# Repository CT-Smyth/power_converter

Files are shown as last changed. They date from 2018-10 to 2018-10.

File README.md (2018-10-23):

VDM power_converter

A control system for controlling cheap power supply bricks (sold commonly as LED drivers, power supplies, etc) to make them suitable for battery charging or other low resistance variable loads. 

The circuit monitors current output from the power supply with a hall effect sensor, and adjusts a digipot which is wired to replace the trimmer pot normally used to adjust output voltage.

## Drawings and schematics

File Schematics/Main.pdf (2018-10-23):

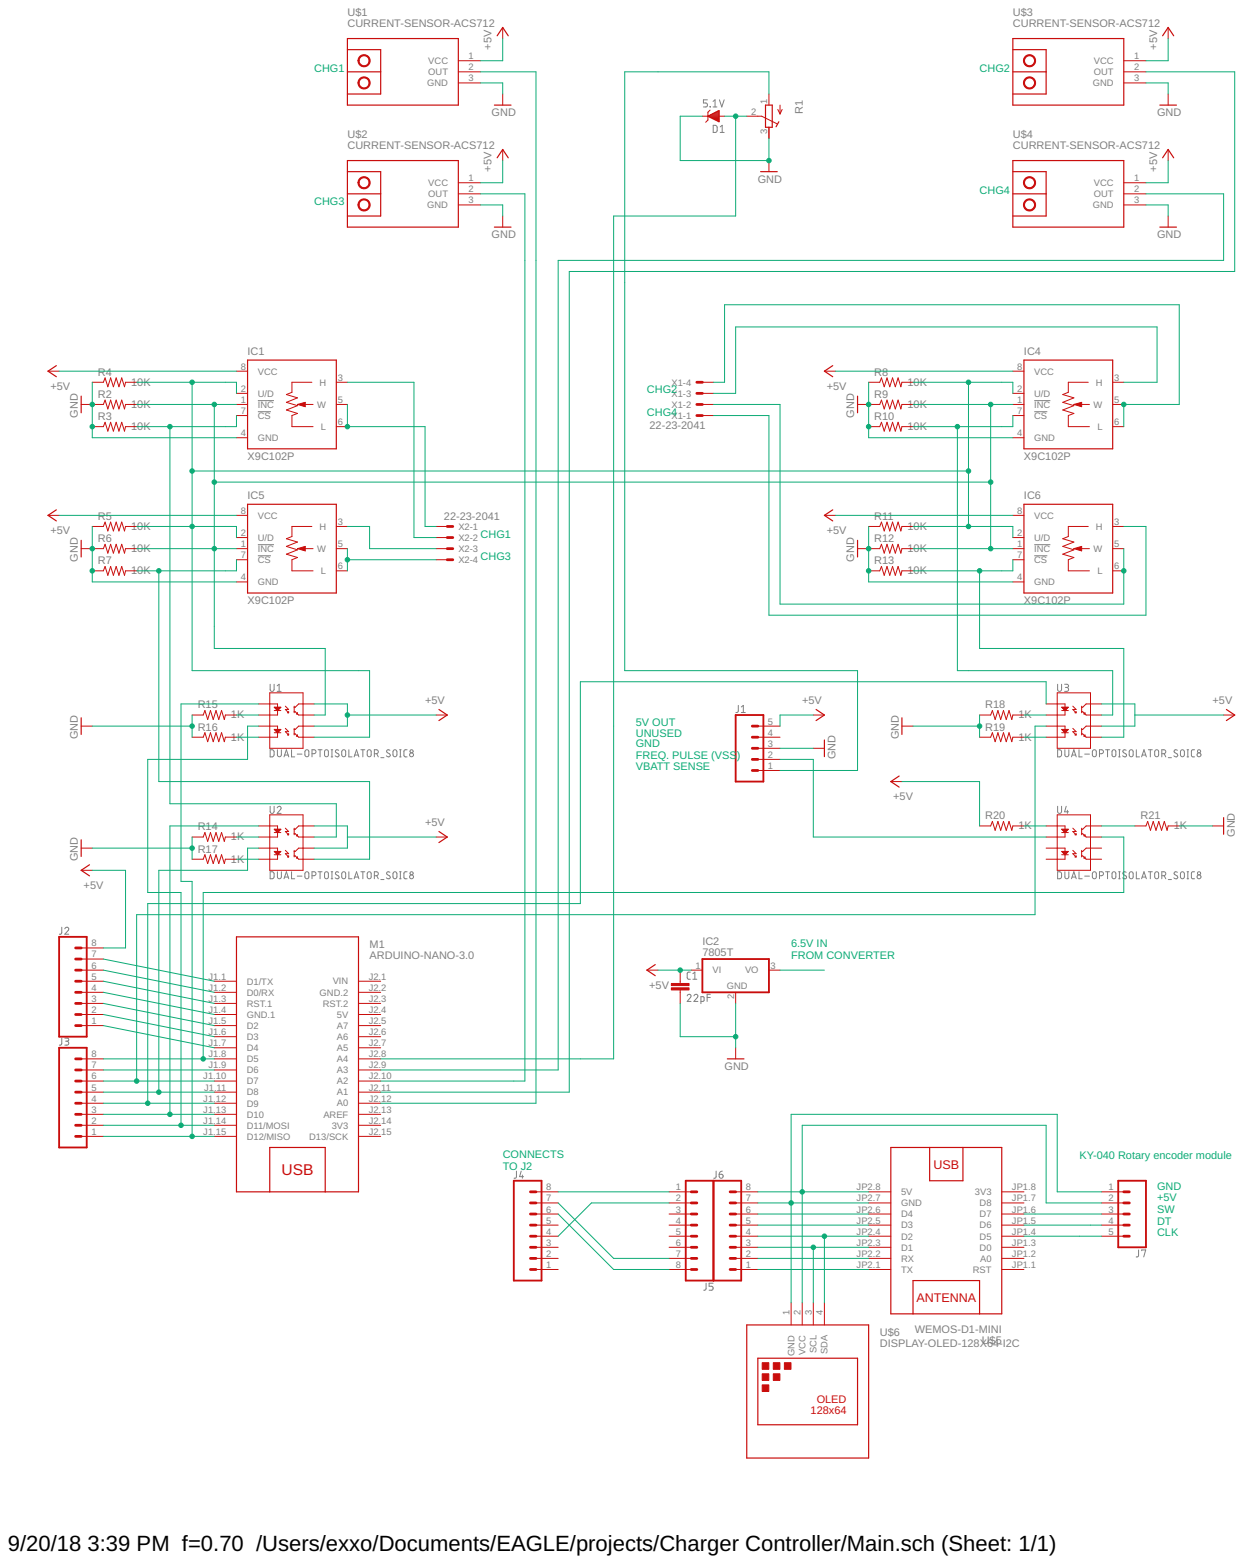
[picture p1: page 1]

FREQ. PULSE (VSS) VBATT SENSE

WEMOS-D1-MINI DISPLAY-OLED-128X64-I2C

9/20/18 3:39 PM f=0.70 /Users/exxo/Documents/EAGLE/projects/Charger Controller/Main.sch (Sheet: 1/1)

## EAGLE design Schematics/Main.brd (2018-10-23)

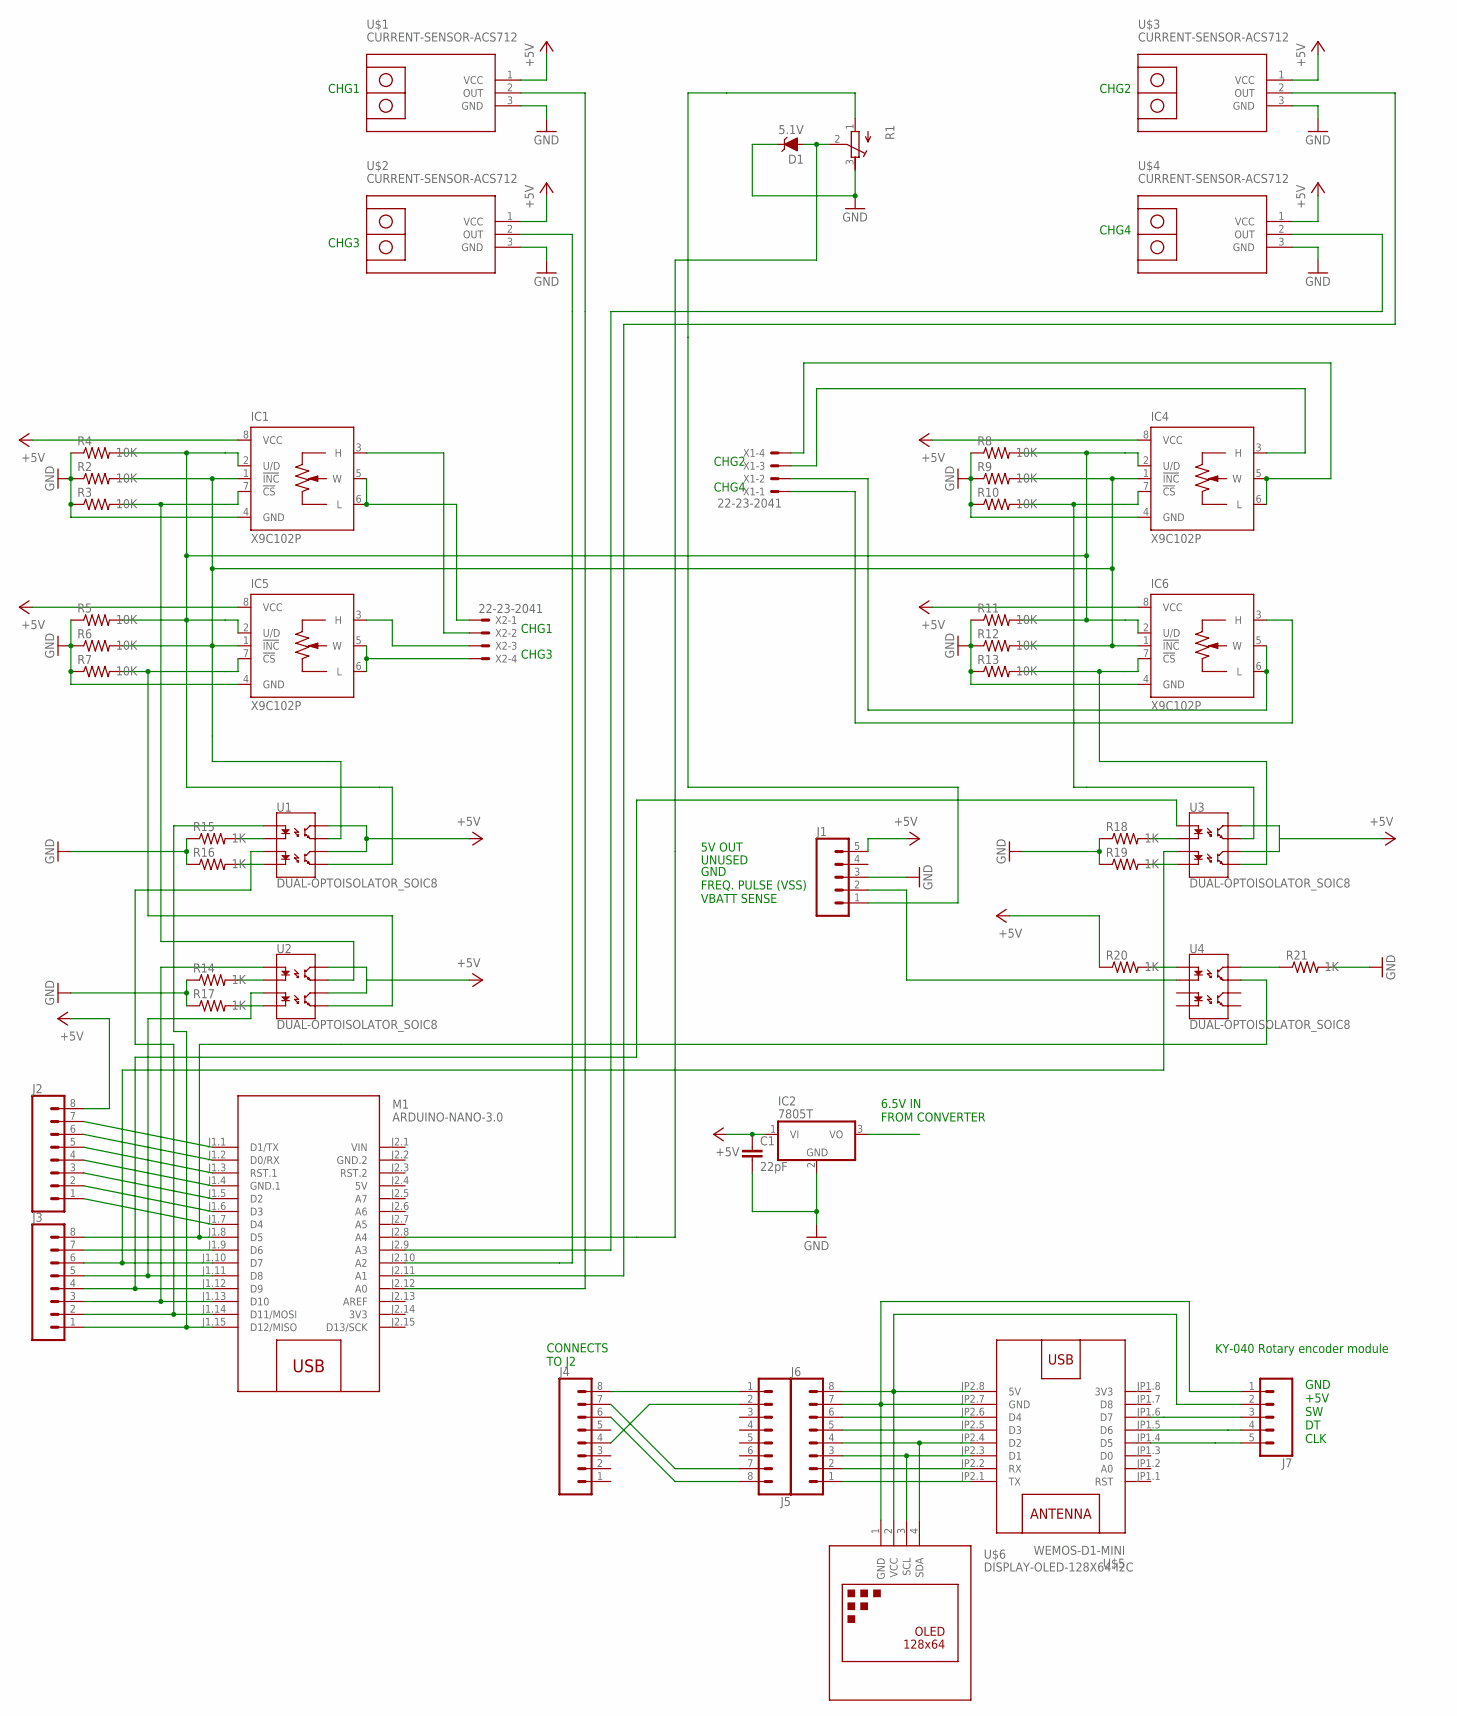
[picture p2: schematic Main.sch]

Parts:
C1: 22pF; CAP-PTH-2.54
D1: 5.1V; SOD-323
IC1, IC4, IC5, IC6: X9C102P; DIL08
IC2: 7805T; TO220H
J1, J7: CONN_05PTH_LONGPADS; 1X05_LONGPADS
J2, J3, J4, J5, J6: CONN_08LONGPADS; 1X08_LONGPADS
M1: ARDUINO-NANO-3.0
R1: R-TRIMM64W; RTRIM64W
R2, R3, R4, R5, R6, R7, R8, R9, R10, R11, R12, R13: 10K; 0204/7
R14, R15, R16, R17, R18, R19, R20, R21: 1K; 0204/7
U1, U2, U3, U4: DUAL-OPTOISOLATOR_SOIC8; SO08
U$1, U$2, U$3, U$4: CURRENT-SENSOR-ACS712
U$5: WEMOS-D1-MINI
U$6: DISPLAY-OLED-128X64-I2C
X1, X2: 22-23-2041

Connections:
3V3: M1.J2.14 (3V3), U$5.JP1.8 (3V3)
5V: M1.J2.4 (5V)
+5V: C1.1, IC1.8 (VCC), IC2.1 (VI), IC4.8 (VCC), IC5.8 (VCC), IC6.8 (VCC), J1.5, J2.8, R20.1, U1.6 (CL2), U1.8 (CL1), U2.6 (CL2), U2.8 (CL1), U3.6 (CL2), U3.8 (CL1), U$1.1 (VCC), U$2.1 (VCC), U$3.1 (VCC), U$4.1 (VCC)
GND: C1.2, D1.C, IC1.4 (GND), IC2.2 (GND), IC4.4 (GND), IC5.4 (GND), IC6.4 (GND), J1.3, R1.3 (E), R2.1, R3.1, R4.1, R5.1, R6.1, R7.1, R8.1, R9.1, R10.1, R11.1, R12.1, R13.1, R14.1, R15.1, R16.1, R17.1, R18.1, R19.1, R21.2, U$1.3 (GND), U$2.3 (GND), U$3.3 (GND), U$4.3 (GND)
GND.2: M1.J2.2 (GND.2)
unnamed: IC1.7 (!CS), R3.2, U2.7 (EM1)
unnamed: IC1.1 (!INC), IC4.1 (!INC), IC5.1 (!INC), IC6.1 (!INC), R2.2, R6.2, R9.2, R12.2, U1.7 (EM1)
unnamed: R15.2, U1.2 (C1)
unnamed: IC1.5 (W), IC1.6 (L), X2.1
unnamed: R16.2, U1.4 (C2)
unnamed: IC5.7 (!CS), R7.2, U2.5 (EM2)
unnamed: IC1.3 (H), X2.2
unnamed: IC1.2 (U/D), IC4.2 (U/D), IC5.2 (U/D), IC6.2 (U/D), R4.2, R5.2, R8.2, R11.2, U1.5 (EM2)
unnamed: IC5.5 (W), IC5.6 (L), X2.4
unnamed: IC5.3 (H), X2.3
unnamed: R14.2, U2.2 (C1)
unnamed: R17.2, U2.4 (C2)
unnamed: IC4.5 (W), IC4.6 (L), X1.4
unnamed: IC6.7 (!CS), R13.2, U3.5 (EM2)
unnamed: R18.2, U3.2 (C1)
unnamed: R19.2, U3.4 (C2)
unnamed: IC6.5 (W), IC6.6 (L), X1.2
unnamed: IC4.3 (H), X1.3
unnamed: IC6.3 (H), X1.1
unnamed: IC4.7 (!CS), R10.2, U3.7 (EM1)
unnamed: J1.2, U4.2 (C1)
unnamed: J1.1, R1.1 (A)
unnamed: D1.A, M1.J2.8 (A4), R1.2 (S)
unnamed: J3.8, M1.J1.8 (D5), U4.7 (EM1)
unnamed: R20.2, U4.1 (A1)
unnamed: R21.1, U4.8 (CL1)
unnamed: J2.1, M1.J1.7 (D4)
unnamed: J2.2, M1.J1.6 (D3)
unnamed: J2.3, M1.J1.5 (D2)
unnamed: J2.4, M1.J1.4 (GND.1)
unnamed: J2.5, M1.J1.3 (RST.1)
unnamed: J2.6, M1.J1.2 (D0/RX)
unnamed: J2.7, M1.J1.1 (D1/TX)
unnamed: J3.1, M1.J1.15 (D12/MISO), U1.1 (A1)
unnamed: J3.2, M1.J1.14 (D11/MOSI), U1.3 (A2)
unnamed: J3.3, M1.J1.13 (D10), U2.1 (A1)
unnamed: J3.4, M1.J1.12 (D9), U3.1 (A1)
unnamed: J3.5, M1.J1.11 (D8), U2.3 (A2)
unnamed: J3.6, M1.J1.10 (D7), U3.3 (A2)
unnamed: J3.7, M1.J1.9 (D6)
unnamed: M1.J2.12 (A0), U$1.2 (OUT)
unnamed: M1.J2.10 (A2), U$2.2 (OUT)
unnamed: M1.J2.11 (A1), U$3.2 (OUT)
unnamed: M1.J2.9 (A3), U$4.2 (OUT)
unnamed: J6.1, U$5.JP2.1 (TX)
unnamed: J6.2, U$5.JP2.2 (RX)
unnamed: J6.3, U$5.JP2.3 (D1), U$6.3 (SCL)
unnamed: J6.4, U$5.JP2.4 (D2), U$6.4 (SDA)
unnamed: J6.5, U$5.JP2.5 (D3)
unnamed: J6.6, U$5.JP2.6 (D4)
unnamed: J6.7, J7.1, U$5.JP2.7 (GND), U$6.1 (GND)
unnamed: J6.8, J7.2, U$5.JP2.8 (5V), U$6.2 (VCC)
unnamed: J4.8, J5.1
unnamed: J4.4, J5.2
unnamed: J4.7, J5.7
unnamed: J4.6, J5.8
unnamed: J7.3, U$5.JP1.6 (D7)
unnamed: J7.4, U$5.JP1.5 (D6)
unnamed: J7.5, U$5.JP1.4 (D5)
VIN: M1.J2.1 (VIN)

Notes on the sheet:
5V OUT
UNUSED
GND FREQ. PULSE (VSS) VBATT SENSE
CHG1
CHG3
CHG2
CHG4
6.5V IN FROM CONVERTER
CONNECTS TO J2
KY-040 Rotary encoder module
GND +5V SW DT CLK

Board: 2 copper layers, 48 parts (0 on the bottom side), 62 nets, no tracks yet.

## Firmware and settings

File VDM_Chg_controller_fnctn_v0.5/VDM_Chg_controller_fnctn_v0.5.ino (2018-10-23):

//for Arduino Nano or ATMega328PA or equivelant
 
//#include <FreqCount.h>

#define INC 12   // D1 Mini D4 - pulled up in H/W (10k) ->  chip pin 1
#define UD 11  // D1 Mini D8                          ->  chip pin 2
#define CS1 10   // D1 Mini D0 - pulled up in H/W (10k) ->  2nd chip pin 7
#define CS2 9
#define CS3 8
#define CS4 7
#define freqPin 5
#define current1Pin A0
#define current2Pin A1
#define current3Pin A2
#define current4Pin A3
#define voltagePin A4


// "up" and "down" make sense in relation to the wiper pin 5 [VW/RW] and the HIGH end of the pot
// i.e. pin 3 [VH/RH], leaving pin 6 [VL/RL] unused (floating). You can easily use pin 6 instead
// pin 3, but "min" will actually mean "max" and vice versa. Also, the "setPot" percentage will
// set the equivalent of 100-<value>, i.e. setPot(70) will set the resistance between pins 5 and 6 
// to 30% of the maximum. (Of course in that case,the "unused" resistance between 5 and 3 will be 70%)
// Nothing to stop you using it as a full centre-tap potentiometer, the above example giving
// pin 3[H] -- 70% -- pin 5[W] -- 30% -- pin 6[L]



bool  bulkMode = true;


int pulseHigh; // Integer variable to capture High time of the incoming pulse
int pulseLow; // Integer variable to capture Low time of the incoming pulse


const int mVperAmp = 66; // use 185 for 5A Module, 100 for 20A Module and 66 for 30A Module
const int ACSoffset = 2500; //2500


int chgMode = 0;



float pulseTotal; // Float variable to capture Total time of the incoming pulse
float frequency; // Calculated Frequency

double Vtrig = 24;
double Vtarg = 27;
double VfloatMin = 26;
double VfloatMax = 26.5;
const double Vmax = 29.5;
const double Vmin = 18;

const double maxCurrent = 15;
const double targetCurrent = 12;



double Voltage = 0;


long num = 0;

unsigned long timeNow = millis();
const unsigned long disp_delay = 1000;
const unsigned long RPM_delay = 400; //2.5 times a second
const unsigned long chg_delay = 255; //4 times a second
unsigned long RPMTimeDue = timeNow + RPM_delay;
unsigned long dispTimeDue = timeNow + disp_delay;
unsigned long chgTimeDue = timeNow + chg_delay;


int incomingByte;      // a variable to read incoming serial data into



void setup(){
pinMode(freqPin,INPUT);

pinMode(INC,OUTPUT);
pinMode(UD,OUTPUT);
pinMode(CS1,OUTPUT);
pinMode(CS2,OUTPUT);
pinMode(CS3,OUTPUT);
pinMode(CS4,OUTPUT);

digitalWrite(UD,HIGH);
digitalWrite(INC,LOW);
digitalWrite(CS1,HIGH);
digitalWrite(CS2,HIGH);
digitalWrite(CS3,HIGH);
digitalWrite(CS4,HIGH);

digitalWrite (freqPin,true); //pullup
//FreqCount.begin(1000);
Serial.begin(57600); 
Serial.println("Energy converter function program");

pinMode(3,OUTPUT); //signal generator for testing
analogWrite(3,75); //signal generator for testing

//analogWrite (12,100);
//analogWrite (11,150);
//analogWrite(10,200);


//pot_1k_setval(1,20); //set these to test POT writing functions
//pot_1k_setval(2,40); //set these to test POT writing functions
//pot_1k_setval(3,60); //set these to test POT writing functions
//pot_1k_setval(4,80); //set these to test POT writing functions


}





void loop() { 

timeNow = millis(); 
  
  
if (Serial.available() > 0) {
    // read the oldest byte in the serial buffer:
    incomingByte = Serial.read();

    if (incomingByte == '0') chgMode = 0;

    if (incomingByte == '1') chgMode = 1;

    if (incomingByte == '2') chgMode = 2;

    if (incomingByte == '3') chgMode = 3;

    
    
//  Serial.print("Operation Mode = ");
//  Serial.println(chgMode);  
}





if (timeNow > chgTimeDue) chargeControl();
if (timeNow > dispTimeDue) one_sec();
// if (timeNow > RPMTimeDue) get_RPM();
 
}

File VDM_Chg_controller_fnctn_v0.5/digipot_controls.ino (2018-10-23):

void pot_down(int potNumber){
  digitalWrite(INC,HIGH); //set up the increment line to increment on low transition & wiper safety
  delayMicroseconds(100);
  digitalWrite(UD,HIGH); //High for up, low for down
  delayMicroseconds(100);
  CS_low (potNumber);
  digitalWrite(INC,LOW); //move wiper as per UD bit
  delayMicroseconds(100);
  CS_high (potNumber);
}

void pot_up(int potNumber){
  digitalWrite(INC,HIGH); //set up the increment line to increment on low transition & wiper safety
  delayMicroseconds(100);
  digitalWrite(UD,LOW); //High for up, low for down
  delayMicroseconds(100);
  CS_low (potNumber);
  digitalWrite(INC,LOW); //move wiper as per UD bit
  delayMicroseconds(100);
  CS_high (potNumber);
}

void pot_store(int potNumber){
  delay(1);
  digitalWrite(INC,HIGH); //set up the increment line to increment on low transition & wiper safety
  delay(1);
  CS_low (potNumber); // Select Chip
  delay(1);
  CS_high (potNumber); //Deselect Chip (stores value because INC is high)
  delay(1);
}


void pot_1k_setval(int potNumber, int val){
  if (val > 100) val = 100;
  if (val < 0) val = 0;
  pot_to_1k(potNumber);
  val = 100 - val;
  for (int t = 0;t<val;t++){
    pot_down(potNumber);
  }  
}

void pot_0k_setval(int potNumber, int val){
  if (val > 100) val = 100;
  if (val < 0) val = 0;
  pot_to_0k(potNumber);
  for (int t = 0;t<val;t++){
    pot_up(potNumber);
  }  
}



void pot_to_1k(int potNumber){
  for (int t = 0;t<101;t++){
    pot_up(potNumber);
  }
}

void pot_to_0k(int potNumber){
  for (int t = 0;t<101;t++){
    pot_down(potNumber);
  }
}

void CS_high(int potNumber){
  
    switch (potNumber) {
    case 1:
      digitalWrite(CS1,HIGH); 
      break;
    case 2:
      digitalWrite(CS2,HIGH);
      break;
    case 3:
      digitalWrite(CS3,HIGH);
      break;
    case 4:
      digitalWrite(CS4,HIGH);
      break;
    default:
      Serial.println("Select_High Selection Error");
  }

  delayMicroseconds(100);
}



void CS_low(int potNumber){
  
    switch (potNumber) {
    case 1:
      digitalWrite(CS1,LOW);
      break;
    case 2:
      digitalWrite(CS2,LOW);
      break;
    case 3:
      digitalWrite(CS3,LOW);
      break;
    case 4:
      digitalWrite(CS4,LOW);
      break;
    default:
      Serial.println("Select_Low Selection Error");
  }

  delayMicroseconds(100);
}

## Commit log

2018-10-23 Added schematics
    [Main.brd, Main.sch]
2018-10-23 Changed filenames to reflect correct versioning
    [Display_subs.ino, Subs.ino, VDM_Chg_controller_fnctn_v0.5.ino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]
2018-10-23 Bug fixes, changed sample rate
    Increased analog sampling duration to ensure that 1/30th of a second is sampled for better accuracy.
    [Subs.ino, VDM_Chg_controller_fnctn_v0.5.ino]
2018-10-23 Directory name change
    [Main.brd, Main.sch]

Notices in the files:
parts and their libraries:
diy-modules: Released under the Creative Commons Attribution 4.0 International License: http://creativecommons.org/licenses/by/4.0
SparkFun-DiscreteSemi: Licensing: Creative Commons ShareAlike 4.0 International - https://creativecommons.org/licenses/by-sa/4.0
